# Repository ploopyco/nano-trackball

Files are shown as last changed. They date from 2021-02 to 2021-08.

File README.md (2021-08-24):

# The Ploopy Nano Trackball

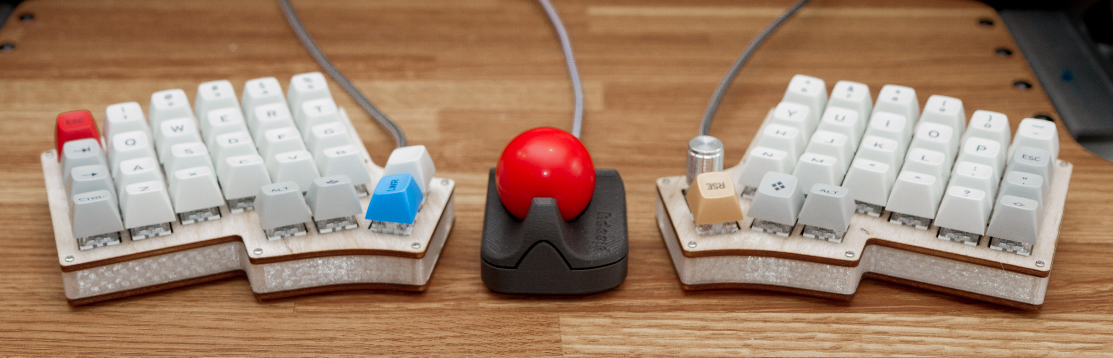
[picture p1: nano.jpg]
The Ploopy Nano Trackball


By some stroke of luck, you've made your way here. The Ploopy Nano Trackball. Your life will never be the same.

This repository contains all of the design and production files necessary to make a Ploopy Nano Trackball. We've also included some kick-ass documentation in the Wiki on how to get it made, assemble it, and program it.

What are you waiting for? Your new life awaits.

## QMK?!

Kits bought from the [Ploopy store](https://ploopy.co/shop/nano-trackball-kit/) come with QMK preloaded. Check out the Wiki for instructions on how to load new firmware onto your device. (It's super easy!)

The firmware hex file that ships with all Nanos is included in this repository as well, as `ploopyco_trackball_nano_rev1_001_default.hex`.

## Under what license is this released?

As per QMK's licensing requirements, the firmware for the Ploopy Nano Trackball is released under GPLv3. Hardware design files, including electronics and mechanical files, are released under OHL CERN v1.2. Check the `LICENSE` file for full license text.

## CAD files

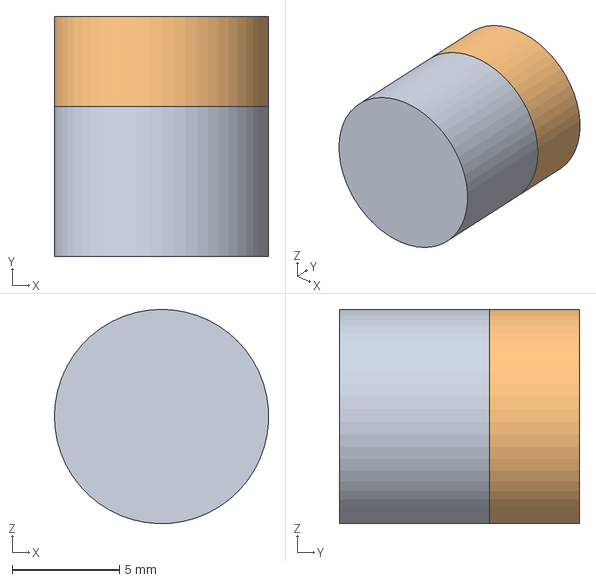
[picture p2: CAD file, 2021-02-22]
hardware/mechanicals/STEPs/Bit Bearing Press Complete.step
9.99 x 11.2 x 10.00 mm

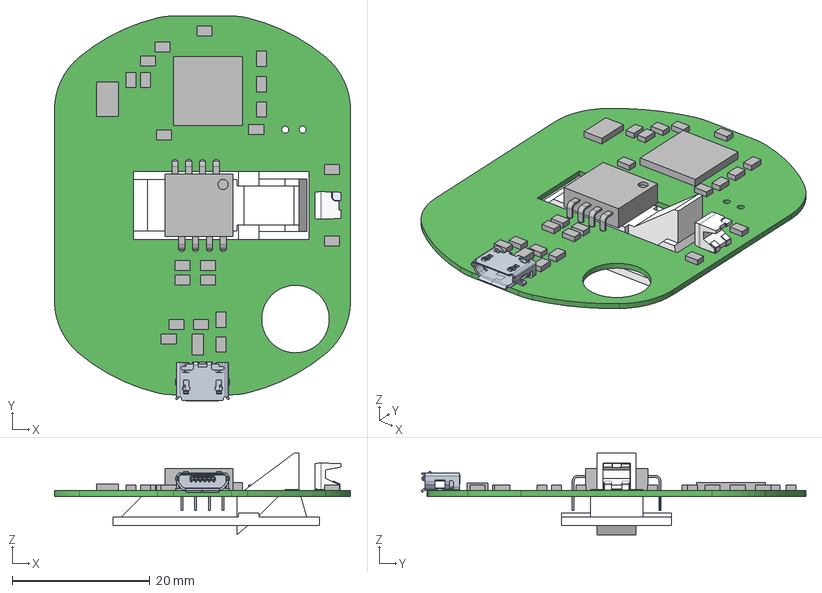
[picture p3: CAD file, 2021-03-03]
hardware/mechanicals/STEPs/PCB.step
43.0 x 55.9 x 11.8 mm
Extruded x 24
10118192C
ADNS-5050
ADNS-5050-Optic
LS_A67F_20091130_geometry_RGB15987699 x 3

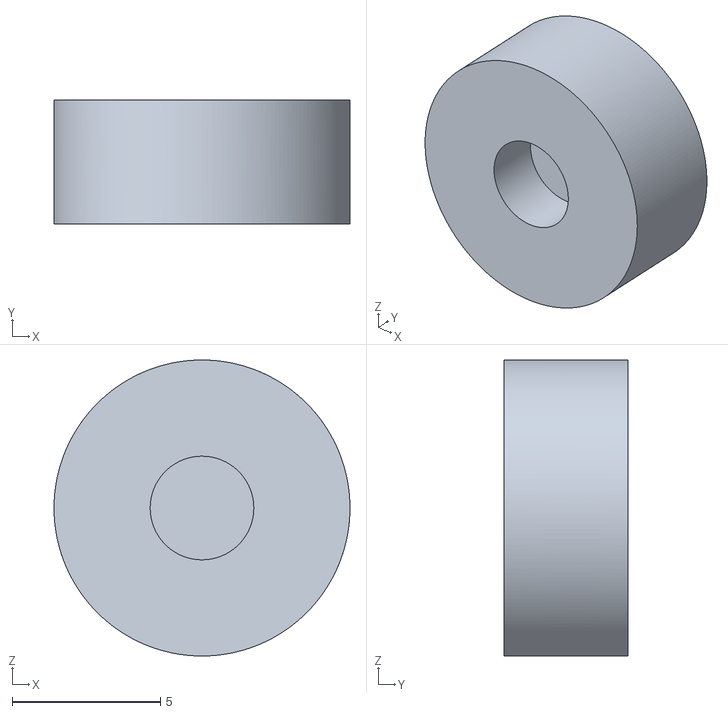
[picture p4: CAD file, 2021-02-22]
hardware/mechanicals/STLs/Kit Bearing Press Top.stl
10.00 x 4.20 x 10.00

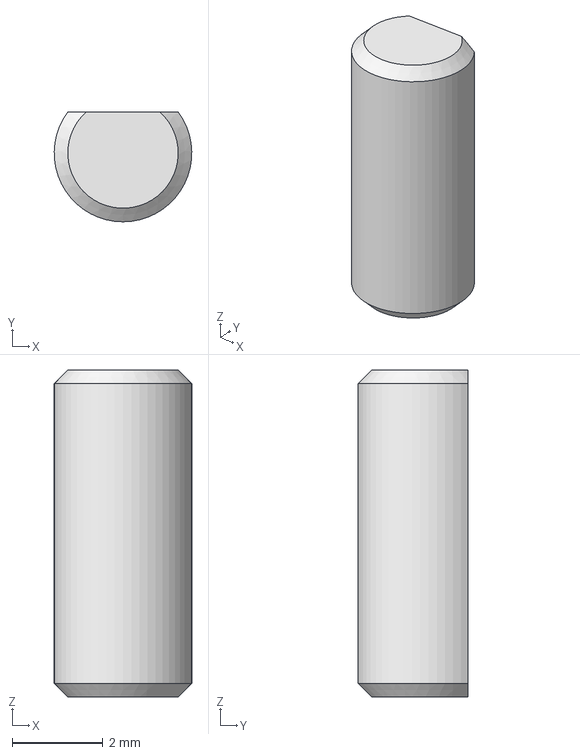
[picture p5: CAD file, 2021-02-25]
hardware/mechanicals/STEPs/RollerBearingDowel.stp
3.03 x 2.42 x 7.20 mm

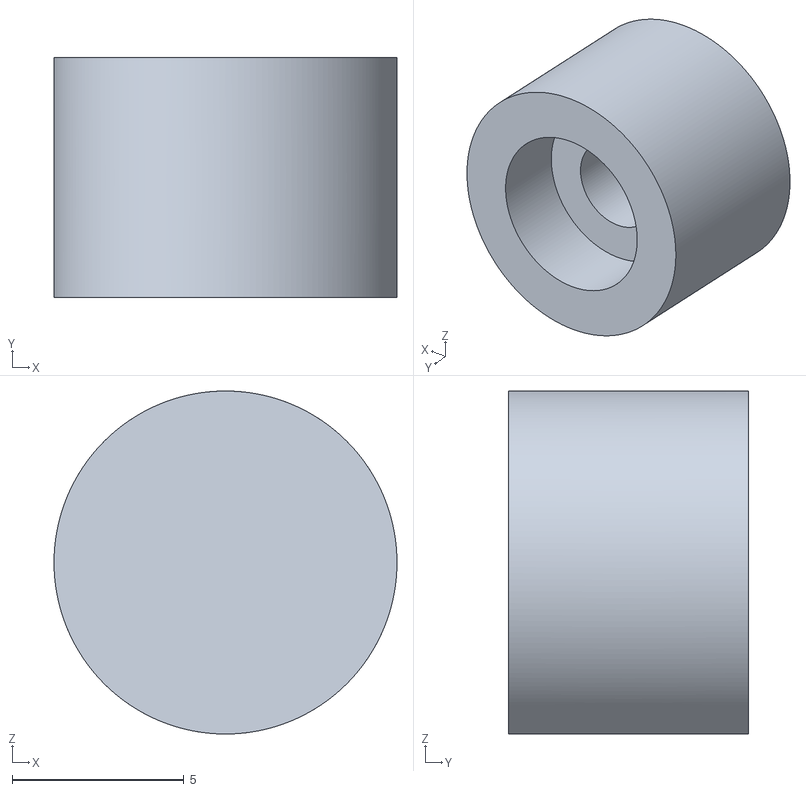
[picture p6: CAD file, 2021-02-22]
hardware/mechanicals/STLs/Kit Bearing Press Bottom.stl
10.00 x 7.00 x 10.00

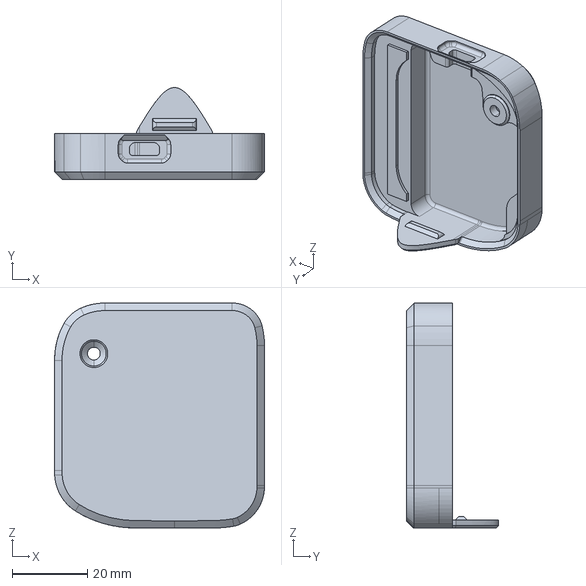
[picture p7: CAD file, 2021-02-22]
hardware/mechanicals/STEPs/Bottom.step
56.0 x 24.5 x 60.0 mm

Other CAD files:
hardware/mechanicals/STLs/Bottom.stl
hardware/mechanicals/STLs/RollerBearingDowel.stl

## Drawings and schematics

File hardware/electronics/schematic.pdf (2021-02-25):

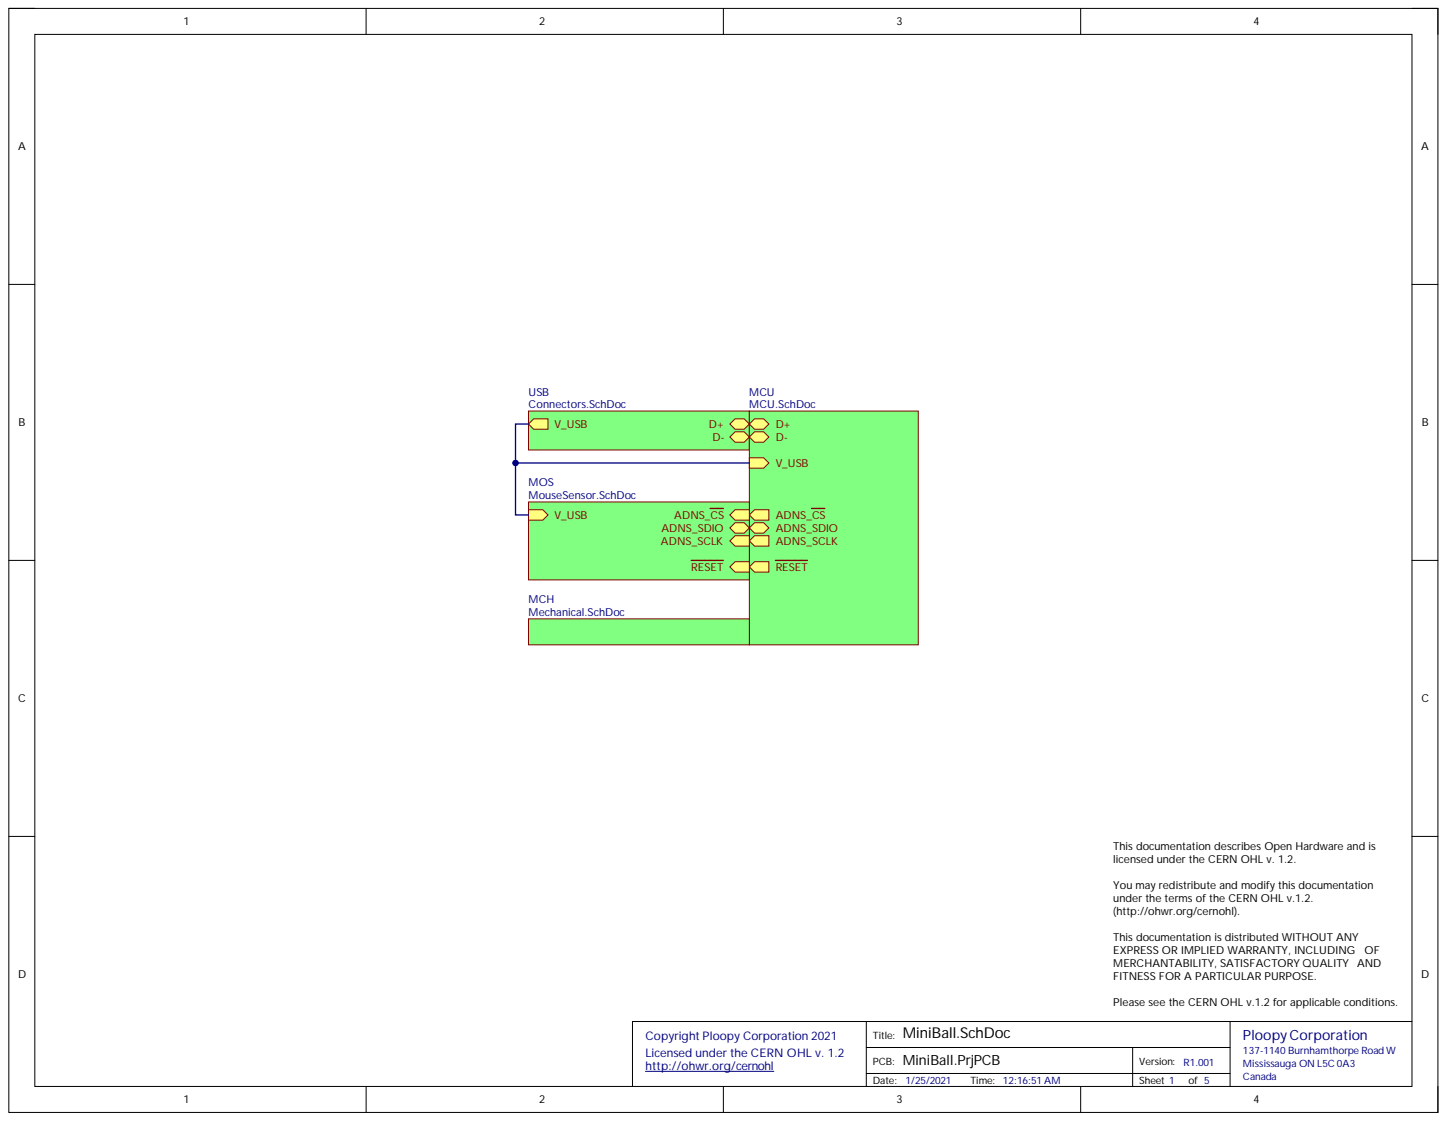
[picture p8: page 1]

V_USB D+ | D+ D-V_USB ADNS_CS ADNS_SDIO ADNS_SCLK RESET

This documentation describes Open Hardware and is
licensed under the CERN OHL v. 1.2.

You may redistribute and modify this documentation
under the terms of the CERN OHL v.1.2.
(http://ohwr.org/cernohl).

This documentation is distributed WITHOUT ANY
EXPRESS OR IMPLIED WARRANTY, INCLUDING OF
MERCHANTABILITY, SATISFACTORY QUALITY AND
FITNESS FOR A PARTICULAR PURPOSE.

Please see the CERN OHL v.1.2 for applicable conditions.

Copyright Ploopy Corporation 2021
Licensed under the CERN OHL v. 1.2
http://ohwr.org/cernohl

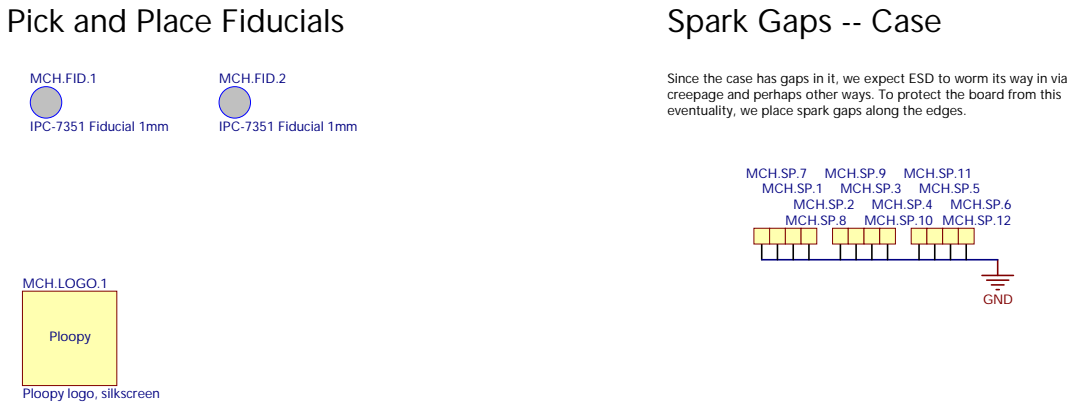
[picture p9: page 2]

Pick and Place Fiducials

Spark Gaps -- Case MCH.SP.7 MCH.SP.1 MCH.SP.8 MCH.SP.2 MCH.SP.9 MCH.SP.3 MCH.SP.10 MCH.SP.4 MCH.SP.1

Since the case has gap
creepage and perhap
eventuality, we place s

s other ways. To protect the board from this
park gap

pect ESD to worm its way in via

Cop
Licensed under the CE
http

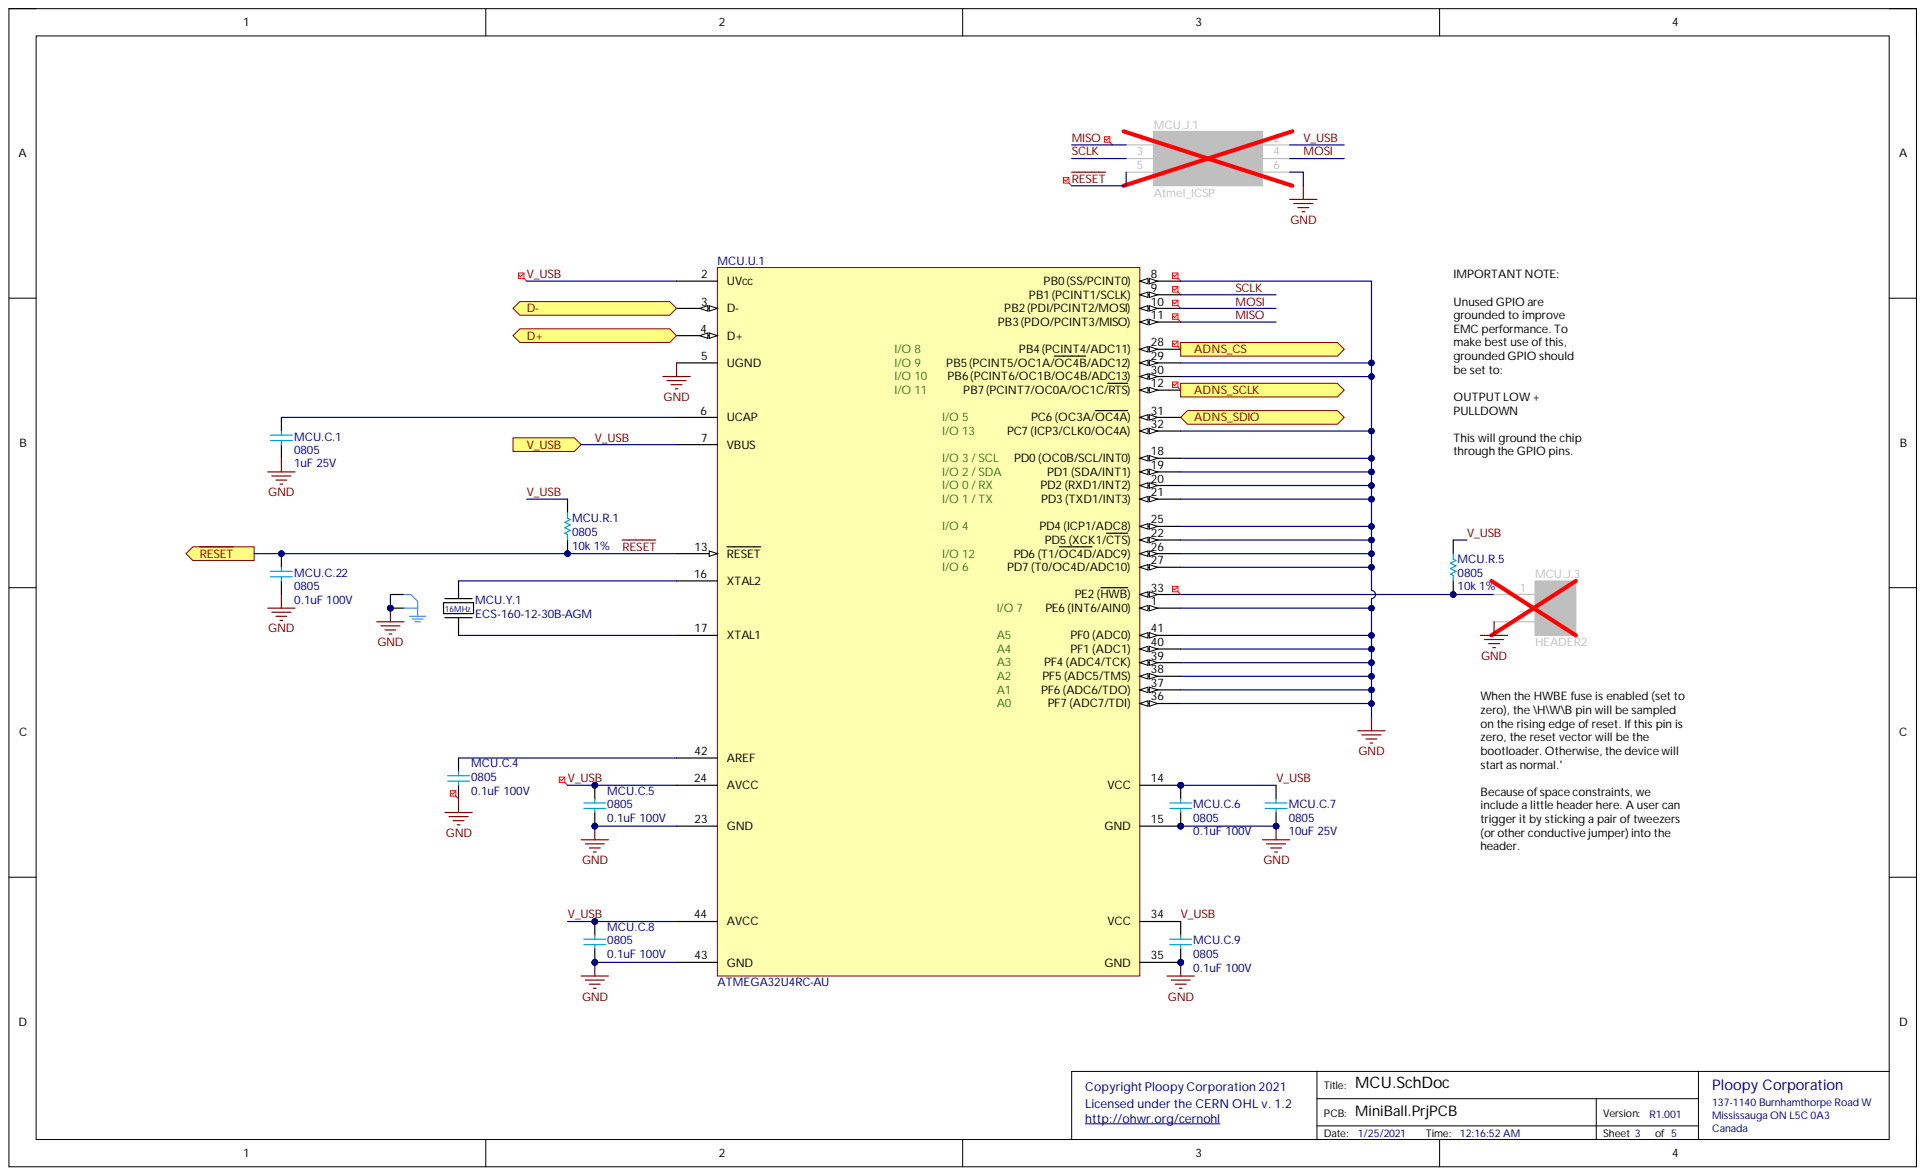
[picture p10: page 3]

Unused GPIO are
grounded to improve
EMC performance. To
make best use of this,
grounded GPIO should
be set to:

This will ground the chip
through the GPIO pins.

When the HWBE fuse is enabled (set to
zero), the \H\W\B pin will be sampled
on the rising edge of reset. If this pin is
zero, the reset vector will be the
bootloader. Otherwise, the device will
start as normal.'

Because of space constraints, we
include a little header here. A user can
trigger it by sticking a pair of tweezers
(or other conductive jumper) into the
header.

Copyright Ploopy Corporation 2021 Licensed under the CERN OHL v. 1.2 http://ohwr.org/cernohl | Title: MCU.SchDoc | Ploopy Corporation 137-1140 Burnhamthorpe Road W Mississauga ON L5C 0A3 Canada

PCB: MiniBall.PrjPCB | Version: R1.001

Date: 1/25/2021 Time: 12:16:52 AM | Sheet 3 of 5

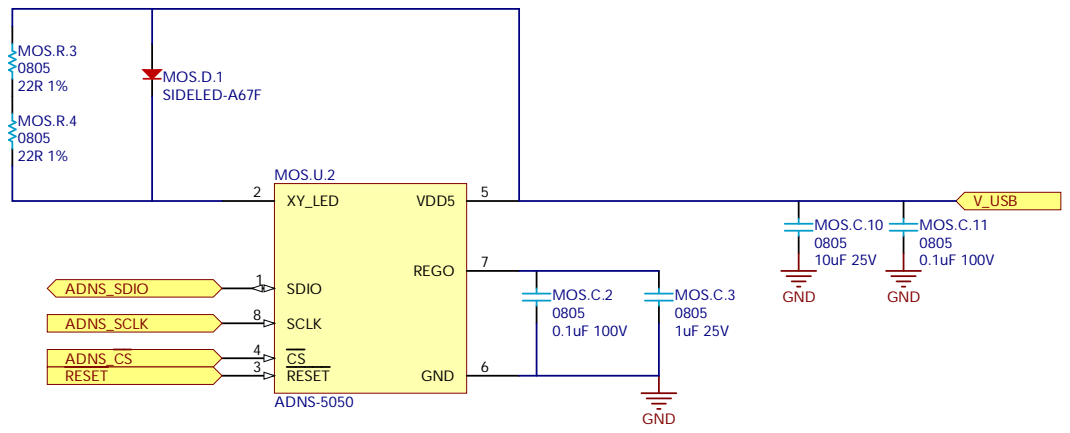
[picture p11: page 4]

Cop
Licensed under the CE
http

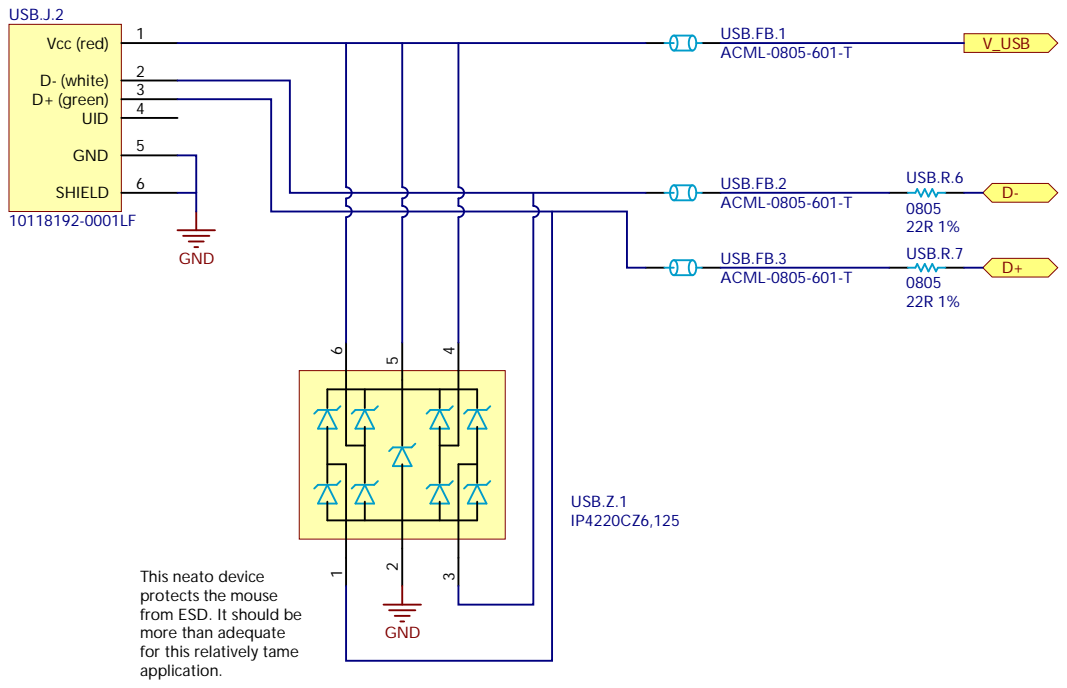
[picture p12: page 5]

This neato device
protects the mouse
from ESD. It should be
more than adequate
for this relatively tame
application.

Copyright Ploopy Corporation 2021
Licensed under the CERN OHL v. 1.2
http://ohwr.org/cernohl

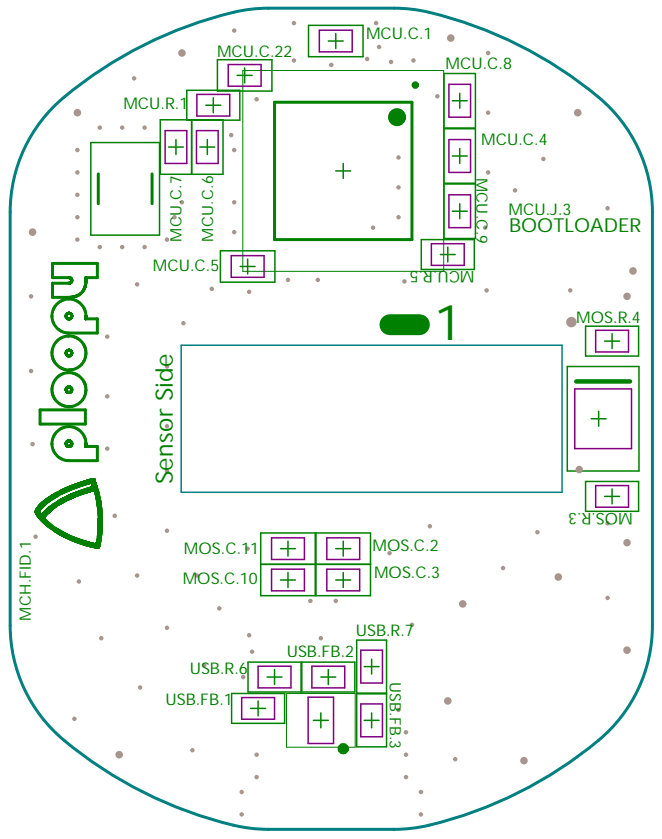
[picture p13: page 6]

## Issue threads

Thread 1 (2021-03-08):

Question: Changes in STL

l4u, 2021-03-08:
What were the changes at https://github.com/ploopyco/nano-trackball/commit/ede7c89742cb379cdbf1e1d8379fff2fd7f83821 ?
I just printed an old version. Is there any major fix?
Thank you!

ploopyco, 2021-03-12:
Yeah, rather large changes. The new version has an offset for the sensor relative to the ball, which makes the ball track better. The old version probably won't work.

Closed 2021-03-12.

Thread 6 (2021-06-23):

Solder pad MOS.U.2-6 is a heat sponge 🧽

somethingelseentirely, 2021-06-23:
MOS.U.2-6 is directly connected to 3 full copper layers, which makes it an insanely good heat sponge when soldering.

I mean, a lot of ground is great, but 3 layers? That's not ground, that's a heat sink. 🤣

TheWerle, 2024-02-07:
The board would benefit greatly from solder-relief on all GND connections, both from the perspective of assembly on Ploopy's end or for utility to end-users.  Grounding all the GPIO to a polygon takes away a ton of potential for kit-bashing for stuff like hand wiring mouse button inputs or integrating a Nano ball into keyboard enclosures Charybdis-style

If you route even a handful of the direct-connected GPIO to test-points then cuttable traces to GND you could achieve the same ESD / floating input protection with far greater utility.  You've open-sourced these badboys, let people cook!

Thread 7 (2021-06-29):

Assembly is easy. also double confirmed the chip orientation. But once done, I plugged in USB, lights on, but the cursor won't move

kevingzhang, 2021-06-29:
Assuming the firmware is pre-flashed into the chip. I expected it works after I plugin the USB cable to my Mac. But I can see the white LED is light but the cursor won't move. Is there extra step I was missing?

breakfastpizza, 2021-07-13:
I had this issue on my Mac and it turned out that my Nano only worked with certain cables. I suggest trying a different cable (I had to try several before I found one that worked) if you haven't already.

kevingzhang, 2021-07-13:
I am no luck. I tried all my cables, none of them work.

jacobrathjens, 2021-08-08:
I am having the same issue, using the cable provided. Are there any other thoughts?

jacobrathjens, 2021-08-08:
To clarify, I'm on Windows, not Mac

kevingzhang, 2021-08-08:
I am using Mac. iPad and Android. Tried several cables. None of them work.
Since there is no refund from seller, I will put it in trash.

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

jacobrathjens, 2021-08-08:
Ok, so I needed to reflow my sensor: second pin from the right on the bottom when you can read the LOTR text.

kevingzhang, 2021-08-09:
Please post here if the problem solved.

jacobrathjens, 2021-08-09:
>
>
> Please post here if the problem solved.

Please refer to my prior comment: the error was a bad join on the sensor. Reflowing the joins resolved the issue.

breakfastpizza, 2021-08-09:
Thanks for sharing @jacobrathjens. My nano has been working well so far but it never hurts to reflow solder so I will go in and reflow my sensor just to be safe.

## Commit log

2021-02-22 design file release
    [Bit Bearing Press Complete.step, Bottom.step, Bottom.stl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]
2021-02-22 added schematic
2021-02-25 added missing roller bearing dowel step and stl
    [RollerBearingDowel.stl, RollerBearingDowel.stp]
2021-03-02 fixed bottom and top models
    [Bottom.stl]
2021-03-03 added PCB step file
    [PCB.step]
